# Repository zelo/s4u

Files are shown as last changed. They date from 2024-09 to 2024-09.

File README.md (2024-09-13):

Some information about Elegoo Saturn 4 Ultra

Everything is provided as is, I'm not responsible for any damage you cause to your hardware. Everything you do is at your own risk!

# Table of Contents

1. [G-code Documentation](gcode.md)
2. [Hardware Documentation](hardware.md)
3. [Anycubic Plate Adapter](anycubic_plate_adapter.md)

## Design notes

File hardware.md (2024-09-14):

# Hardware (from boot log analysis)

**Hardware Components**

| **Component** | **Details** | **Additional Information & Links** |
|---|---|---|
| **SoC** | **SigmaStar SSD202D** | - Dual-core ARM Cortex-A7 CPU<br>- 128 MB DDR RAM<br>- Integrated peripherals including Ethernet, USB, and more<br>- [SigmaStar SSD202D Documentation](https://github.com/iscle/SigmaStar-SSD202D-Docs/tree/main)<br>- [Linux Support Information](https://linux-chenxing.org/infinity2/#ssd202d) |
| **Storage** | **8 GB eMMC - Samsung KLM8G1GETF-B041** | - eMMC 5.1 standard<br>- High performance and reliability for embedded applications<br>- [Samsung KLM8G1GETF-B041 Product Page](https://semiconductor.samsung.com/estorage/emmc/emmc-5-1/klm8g1getf-b041/) |
| **FPGA** | **WILNX17 BG256** | - FPGA device by Jing Zhong Semiconductor<br>- Specific datasheet unavailable<br>- [WILNX17 BG256 Product Page](https://jingzhongsemi.com/cn/product/WILNX17.html) |
| **Wi-Fi Module** | **Realtek RTL8811CU** | - Supports 802.11ac Wi-Fi standard<br>- USB interface<br>- Provides wireless connectivity<br>- [Realtek RTL8811CU Product Page](https://www.realtek.com/en/products/communications-network-ics/item/rtl8811cu)<br>- [Datasheet](https://www.lcsc.com/datasheet/lcsc_datasheet_2302141730_Realtek-Semicon-RTL8811CU-CG_C2687136.pdf) |
| **Touchscreen** | **Goodix Capacitive Touchscreen (Goodix-TS 1-005d)** | - Identified in boot log<br>- Likely used for user input<br>- [Goodix Touchscreen Controllers](https://www.goodix.com/en/products/touchscreen-controllers) |
| **Display Panel** | **LCD Display with Resolution 480x800** | - Display output for user interface<br>- Rotation capabilities |
| **Camera** | **UVC-Compliant HD Camera (UC01 HD Camera)** | - USB-connected camera<br>- Used for monitoring or scanning<br>- [UVC Devices Information](https://www.kernel.org/doc/html/latest/userspace-api/media/uvcvideo.html) |
| **USB Ports** | **Multiple USB 2.0 EHCI Controllers** | - Enables connection of USB devices<br>- Managed by EHCI drivers |
| **Ethernet Interface** | **Ethernet Controller (sstar_emac)** | - Integrated Ethernet MAC in SoC<br>- Not exposed as port |
| **Stepper Motor Drivers** | **TMC2209 and FQ6630 Stepper Motor Drivers** | - Used for precise motor control<br>- Common in 3D printers for axis movement<br>- **TMC2209**: [Datasheet](https://www.trinamic.com/fileadmin/assets/Products/ICs_Documents/TMC2209_datasheet.pdf)<br>- **FQ6630**: Datasheet not readily available |
| **Temperature Sensor** | **Onboard Temperature Sensor** | - Monitors device temperature<br>- Reports around 30°C in logs |
| **I2C Devices** | **I2C Bus Devices** | - Communication with peripherals<br>- Notable error with device at address `0x82` |
| **GPIO Interfaces** | **General Purpose Input/Output Pins** | - Used for hardware control<br>- Configured during boot (`gpio debug` messages) |
| **Storage Partitions** | **Multiple MTD Partitions on SPI NAND Flash** | - 128 MiB SPI NAND Flash<br>- Partitions include `KERNEL`, `UBI`, etc. |
| **MMC Interfaces** | **MicroSD/MMC Card Interface** | - eMMC storage (`mmcblk0`)<br>- Supports additional storage options |

# Boot Log Analysis (based on boot.log file by ChatGPT)

1. Boot Process Overview

    The device undergoes the following boot sequence:

    Initial Program Loader (IPL): Begins with IPL g75a3331, indicating the bootloader version.
    U-Boot Bootloader:
        Version: U-Boot 2015.01
        Build Date: July 03, 2024
        Build Info: Build: jenkins-PPL_100-PACKAGE-OS-CL103-811
    Linux Kernel:
        Version: 4.9.84
        Build Date: July 03, 2024
        Processor: ARM Cortex-A7 (ARMv7 Processor [410fc075] revision 5)
    Filesystem:
        Root filesystem mounted as UBIFS from UBI volume.

2. Hardware Details

   CPU: ARM Cortex-A7 (dual-core)
   Memory:
   RAM: 128 MB
   eMMC Storage: 7.28 GiB (mmcblk0)
   Flash Storage:
   Type: SPI NAND (SPINAND)
   Size: 128 MiB
   Partitions: 13 MTD partitions (e.g., IPL0, UBOOT0, KERNEL, UBI)
   Peripherals:
   Touchscreen: Goodix Capacitive TouchScreen (Goodix-TS 1-005d)
   Camera: UVC-compliant camera detected (UC01 HD Camera)
   USB Ports: Multiple USB EHCI controllers initialized
   Network Interfaces:
   Ethernet: sstar_emac driver
   Wi-Fi: Realtek 802.11ac NIC (rtl8821cu driver)
   Sensors:
   Temperature Sensor: Reports temperatures around 30°C

3. Software Components

   Operating System: Embedded Linux
   Bootloader: U-Boot
   Kernel Modules:
   Various modules are attempted to load (e.g., exfat.ko, uvcvideo)
   Services and Applications:
   Networking: udhcpc DHCP client, Wi-Fi supplicant
   RTSP Server: Streams video from the camera
   WebSocket Listener: Runs on ws://0.0.0.0:3030/websocket
   Custom Applications: Indications of custom applications like ai_camera, sdcp_v3, and others

4. Device Functionality

    Based on the log entries, the device appears to be a 3D printer with the following features:

    Motion Control:
        Axes: References to axis, stepper, endstop, and homing procedures
        Motor Drivers: tmc2209, fq6630 (common stepper motor drivers)
    Printing Parameters:
        Layer Information: CurrentLayer, TotalLayer
        Print Screen: PrintScreen value indicates progress or status
    FPGA Integration:
        FPGA Initialization: Logs related to fpga, suggesting use for real-time control
    User Interface:
        Touchscreen Input: Goodix touchscreen driver initialized
        Display Output: References to framebuffer and display settings

5. Network Connectivity

   Wi-Fi Connection:
   Connects to a Wi-Fi network with DHCP
   Obtains IP address and DNS information
   Server Connections:
   Communicates with mms.chitubox.com, indicating possible firmware updates or telemetry
   Attempts to start services like ws_client_register

6. Errors and Warnings

   Service Startup Failures:
   syslogd, klogd, and mdev fail to start due to missing start-stop-daemon
   Logs:
   /etc/init.d/S01syslogd: line 16: start-stop-daemon: not found
   Similar errors for S02klogd and S10mdev
   Module Loading Failures:
   Unable to insert certain kernel modules
   Logs:
   insmod: can't insert '/config/modules/4.9.84/exfat.ko': No such file or directory
   Similar errors for videodev.ko, v4l2-common.ko, etc.
   Filesystem Mounting Issues:
   Errors mounting partitions with NTFS and exFAT filesystems
   Logs:
   NTFS signature is missing. Failed to mount '/dev/mmcblk0p1': Invalid argument
   FAT-fs (mmcblk0p1): utf8 is not a recommended IO charset for FAT filesystems
   I2C Communication Errors:
   Unable to communicate with a device at address 0x82
   Logs:
   ERROR: Bus[0] in ms_i2c_xfer_write: Slave dev NAK, Addr: 0x82
   USB Device Issues:
   Errors related to USB device descriptors
   Logs:
   usb_get_configuration_no: failed to get descriptor - too long: 1992
   Other Warnings:
   WARNING: Caches not enabled during DRAM initialization
   hctosys: unable to open rtc device (rtc0)

7. Recommendations

   Service Failures:
   Ensure that start-stop-daemon is installed and properly located in the system PATH.
   Verify scripts in /etc/init.d/ reference the correct paths.
   Kernel Modules:
   Check that all necessary kernel modules are present in /config/modules/4.9.84/.
   Rebuild or install missing modules if necessary.
   Filesystem Mounting:
   Install necessary filesystem drivers for NTFS and exFAT if support for these filesystems is required.
   Ensure that the mount command is used with correct options matching the filesystem type.
   I2C Device at Address 0x82:
   Investigate the device connected at I2C address 0x82.
   Check for hardware connectivity issues or device malfunctions.
   USB Devices:
   Ensure that connected USB devices are compatible and functioning correctly.
   Update USB drivers if necessary.

8. Additional Observations

   Device Identity:
   References to ELEGOO and CHITUBOX suggest the device is an ELEGOO 3D printer using Chitu firmware.
   Logs:
   curl url : https://mms.chitubox.com/mainboardVersionUpdate/getInfo.do7?machineType=ELEGOO
   Security Considerations:
   The boot log ends with a login prompt: (none) login:
   Ensure that default passwords are changed to secure the device.
   Consider disabling unnecessary services if not required.

9. Conclusion

    The boot log indicates that the device is a network-connected 3D printer with various peripherals and services. There
    are some issues during boot, primarily related to missing executables and kernel modules. Addressing these issues will
    improve system stability and functionality.

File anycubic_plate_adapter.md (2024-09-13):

# Adapter for anycubic Mono X plate (mine is from mono X 6K)

You will need to replace locking mechanism with insert (need ti print part, hex nut, 2 threaded inserts and 2 screws)
Adapter uses friction fit, I printed mine with PLA 5 walls, 100% infill on bambulab x1c and it fits perfectly.
Printer settings have to be adjusted to account for difference in height [See My Settings](examples/update.gcode)

1. [Step File](anycubic_plate_adapter.step)
2. Images
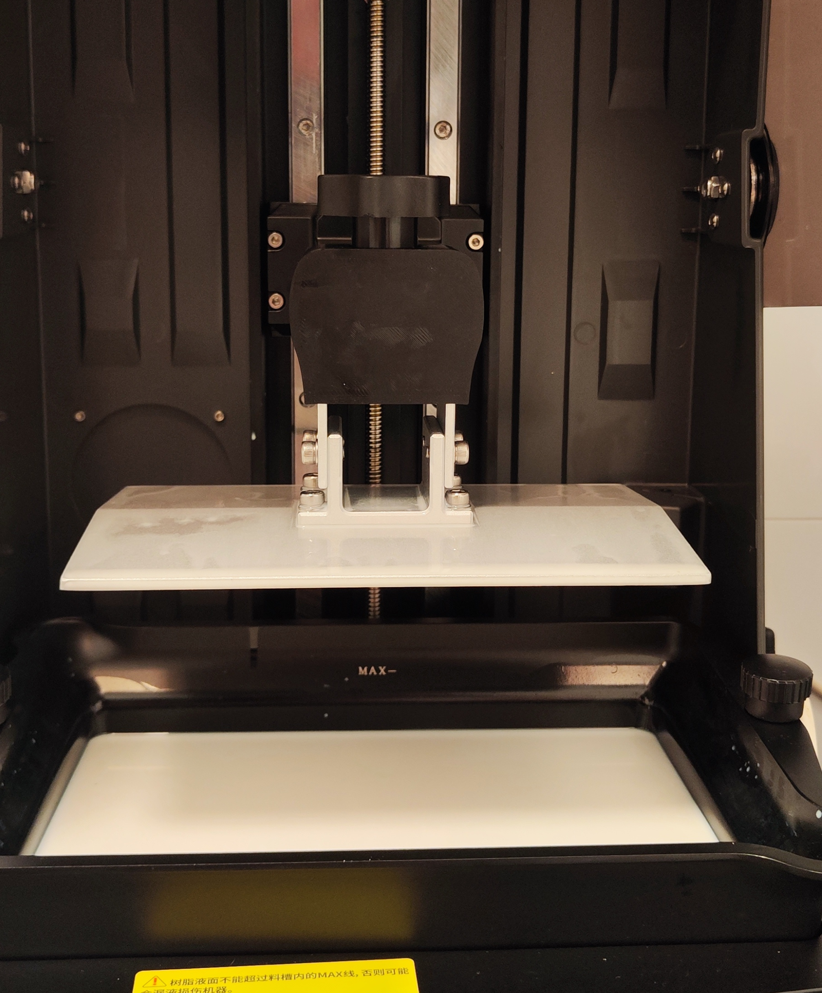
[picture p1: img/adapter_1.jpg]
adapter image 1
   
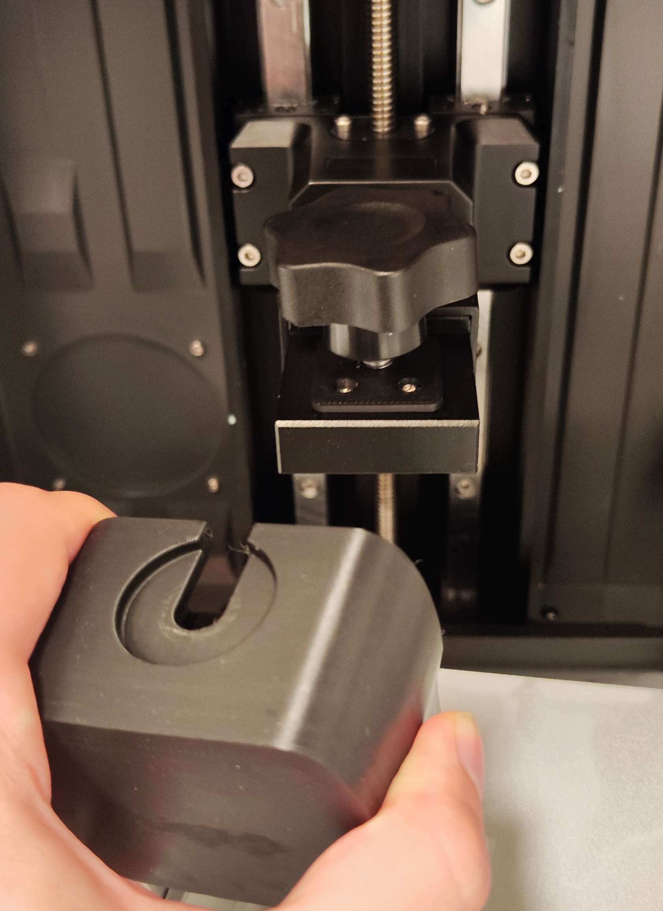
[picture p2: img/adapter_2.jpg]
adapter image 2
   
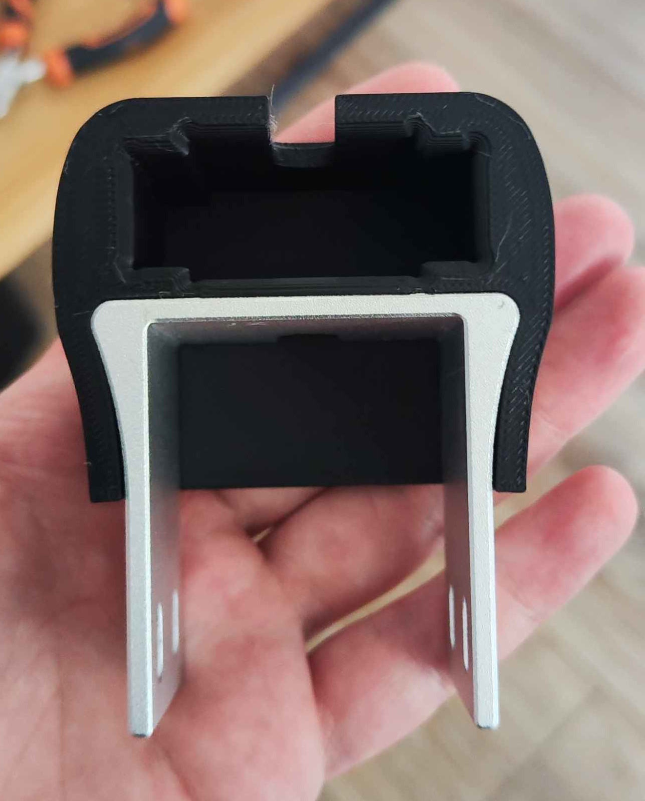
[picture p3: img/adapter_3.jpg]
adapter image 3
   
3. Results
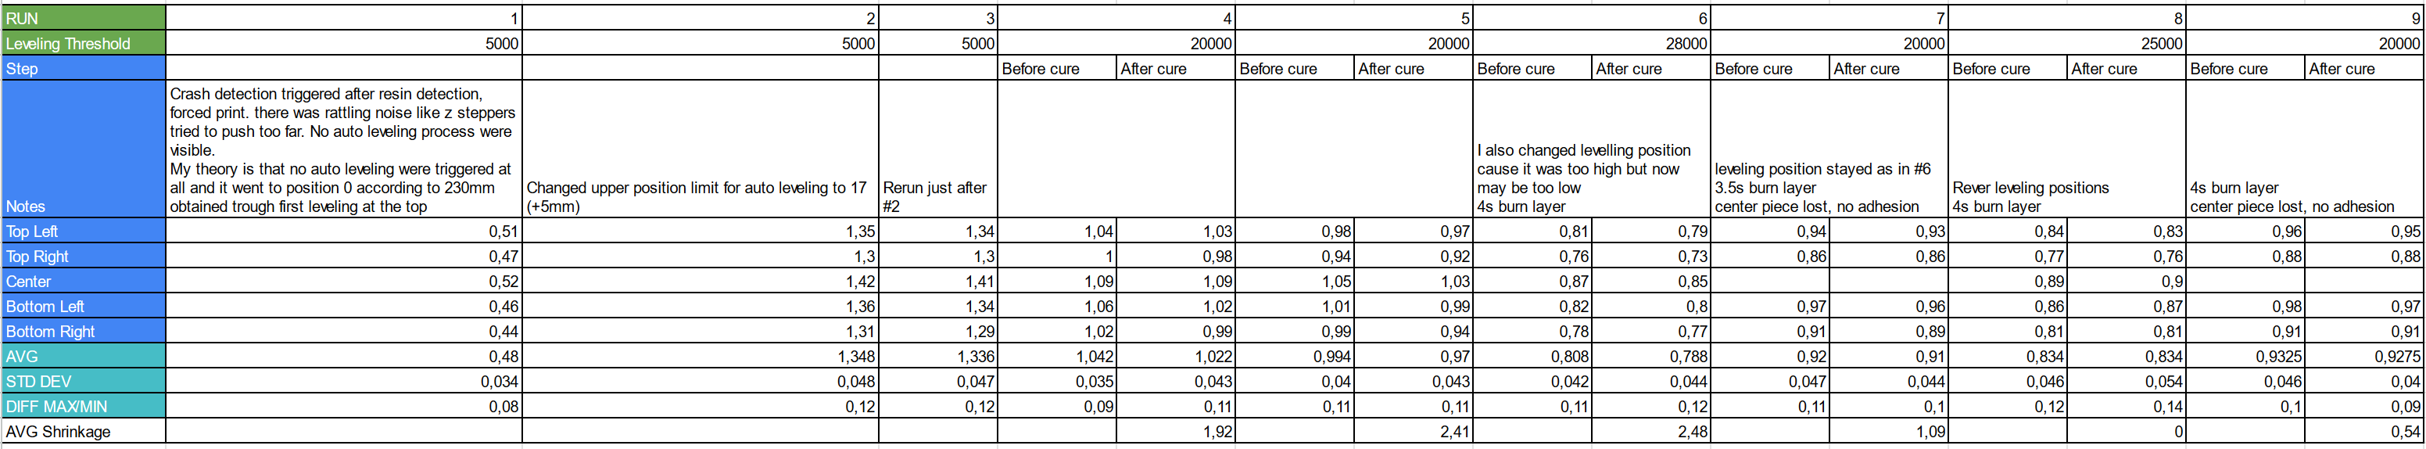
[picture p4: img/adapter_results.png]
Adapter Results


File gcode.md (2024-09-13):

# GCode settings

## **M5999 - Save and Export Machine Parameters**

The `M5999` command is used to manage the printer's configuration parameters, either saving them or exporting them to an
external storage device (such as a USB drive).

### **Command Structure:**

```
M5999 I<number> ; <comment>
```

- **M5999**: Command to either save or export the machine parameters.
- **I<number>**: Defines the action to be taken (save or export).
- **; <comment>**: Optional comment explaining the action.

### **Parameters:**

- **I0**: **Save machine parameters**
    - Example: `M5999 I0 ;保存参数`
    - **Translation**: "Save parameters"
    - **Description**: This command saves the current machine parameters to the printer's internal memory. These
      parameters include all the settings related to axis movements, motor currents, homing speeds, and other system
      configurations. The command ensures that the current configurations are stored and will persist after a restart.

- **I1**: **Export machine parameters to USB**
    - Example: `M5999 I1 ;导出机器参数`
    - **Translation**: "Export machine parameters"
    - **Description**: This command exports the current machine parameters to USB drive with
      filename `100MachineParams.gcode`.

---

### **Usage:**

1. **create `dump.gcode` file on usb with below content**
    ```
   M5999 I0;
   M5999 I1;
   ```

2. **Print this file on your printer**
3. **Open `100MachineParams.gcode` from USB on your PC**

Here’s a comprehensive and detailed breakdown of the `M5000` commands in your MSLA resin printer G-code configuration
file, including explanations for each parameter and possible use cases. This documentation will help you understand what
each command does and how it affects your printer.

---

# **MSLA Resin Printer G-code Command Documentation**

Sure! Below is a table that organizes the settings from your G-code dump, translating the Chinese comments into English
and grouping them by the domain they control.

---

### **Z-Axis Settings**

| Command | Parameters | Description |
|---|---|---|
| M5000 I0 A0 B230.000000 | B230.000000 | Z-axis travel distance (mm) |
| M5000 I0 A0 C20.000000 | C20.000000 | Maximum speed of Z-axis motor (mm/s) |
| M5000 I0 A0 D0.000625000000 | D0.000625000000 | Distance per step for Z-axis motor (mm/step) |
| M5000 I0 A0 E1 | E1 | Z-axis motor direction; 1 for positive, -1 for negative |
| M5000 I0 A0 F1 | F1 | Z-axis limit mode; 0: minimum limit, 1: maximum limit, 2: dual limit |
| M5000 I0 A0 S1 | S1 | Z-axis homing direction; 1 for positive, -1 for negative |
| M5000 I0 A0 P4.500000 | P4.500000 | First-stage homing speed for Z-axis (mm/s) |
| M5000 I0 A0 R1.000000 | R1.000000 | Second-stage homing speed for Z-axis (mm/s) |
| M5000 I0 A0 T0.000000 | T0.000000 | Reverse movement distance before Z-axis homing (mm); used to prevent collision if limit switch is far from physical zero point |
| M5000 I0 A0 X5.000000 | X5.000000 | Reverse movement distance after first limit trigger during Z-axis homing (mm) |
| M5000 I0 A0 Y0.450001 | Y0.450001 | Z-axis zero position |
| M5000 I0 A0 Z1 | Z1 | Z zero point and limit position setting; 0: same as limit position, 1: different from limit position |
| M5000 I5 A0 B0 | B0 | Z-axis minimum limit polarity; 0 for low-level trigger, 1 for high-level trigger |
| M5000 I5 A0 C0 | C0 | Z-axis maximum limit polarity; 0 for low-level trigger, 1 for high-level trigger |
| M5000 I5 A0 D5.000000 | D5.000000 | Z-axis acceleration (mm/s²) |
| M5000 I5 A0 E0.050000 | E0.050000 | Initial speed of Z-axis (mm/s) |
| M5000 I6 F9 | F9 | Z-axis motor current at idle (0-31); Current = (N+1)/32 * 2.5 A |
| M5000 I6 S18 | S18 | Z-axis motor operating current (0-31); Current = (N+1)/32 * 2.5 A |

### **X-Axis Settings**

| Command | Parameters | Description |
|---|---|---|
| M5000 I6 A12 | A12 | X-axis motor current at idle (0-31); Current = (N+1)/32 * 2.5 A |
| M5000 I6 B25 | B25 | X-axis motor operating current (0-31); Current = (N+1)/32 * 2.5 A |
| M5000 I6 C36.000000 | C36.000000 | X-axis acceleration (degrees/s²) |
| M5000 I6 D36.000000 | D36.000000 | X-axis deceleration (degrees/s²) |
| M5000 I6 E36.000000 | E36.000000 | Initial speed of X-axis (degrees/s) |
| M5000 I6 P1 | P1 | X-axis current change step value per time (1-31) |
| M5000 I6 R1000 | R1000 | X-axis current change interval (ms) |
| M5000 I0 A1 B140.000000 | B140.000000 | Total peeling angle of X-axis (degrees) |
| M5000 I0 A1 C900.000000 | C900.000000 | Maximum speed of X-axis motor (degrees/s) |
| M5000 I0 A1 D0.007031250000 | D0.007031250000 | Angle per step for X-axis motor (degrees/step) |
| M5000 I0 A1 E1 | E1 | X-axis motor direction; 1 for positive, -1 for negative |
| M5000 I0 A1 F1 | F1 | X-axis limit mode; 0: minimum limit, 1: maximum limit, 2: dual limit |
| M5000 I0 A1 S1 | S1 | X-axis homing direction; 1 for positive, -1 for negative |
| M5000 I0 A1 P36.000000 | P36.000000 | First-stage homing speed for X-axis (degrees/s) |
| M5000 I0 A1 R36.000000 | R36.000000 | Second-stage homing speed for X-axis (degrees/s) |
| M5000 I0 A1 T0.000000 | T0.000000 | Reverse movement angle before X-axis homing (degrees); used to prevent collision |
| M5000 I0 A1 X60.000000 | X60.000000 | Reverse movement angle after first limit trigger during X-axis homing (degrees) |
| M5000 I0 A1 Y0.000000 | Y0.000000 | X-axis zero position |
| M5000 I0 A1 Z1 | Z1 | X zero point and limit position setting; 0: same as limit position, 1: different from limit position |
| M5000 I5 A1 B0 | B0 | X-axis minimum limit polarity; 0 for low-level trigger, 1 for high-level trigger |
| M5000 I5 A1 C0 | C0 | X-axis maximum limit polarity; 0 for low-level trigger, 1 for high-level trigger |
| M5000 I201 C40.000000 | C40.000000 | Manual control speed of X-axis (degrees/s) |
| M5000 I201 D-10.000000 | D-10.000000 | Maximum zero position of X-axis; the range for adjustment after homing (degrees) |

### **Layer Settings for X-Axis**

| Command | Parameters | Description |
|---|---|---|
| M5000 I200 A36.000000 | A36.000000 | First-stage return speed before N layers (high speed) (degrees/s) |
| M5000 I200 B36.000000 | B36.000000 | Second-stage return speed before N layers (low speed) (degrees/s) |
| M5000 I200 C36.000000 | C36.000000 | First-stage peeling speed before N layers (low speed) (degrees/s) |
| M5000 I200 D36.000000 | D36.000000 | Second-stage peeling speed before N layers (high speed) (degrees/s) |
| M5000 I200 E0.000000  | E0.000000  | Second-stage return angle before N layers (degrees) |
| M5000 I200 F0.000000  | F0.000000  | First-stage peeling angle before N layers (degrees) |
| M5000 I200 S72.000000 | S72.000000 | First-stage return speed after N layers (high speed) (degrees/s) |
| M5000 I200 P72.000000 | P72.000000 | Second-stage return speed after N layers (low speed) (degrees/s) |
| M5000 I200 R72.000000 | R72.000000 | First-stage peeling speed after N layers (low speed) (degrees/s) |
| M5000 I200 T72.000000 | T72.000000 | Second-stage peeling speed after N layers (high speed) (degrees/s) |
| M5000 I200 X0.000000  | X0.000000  | Second-stage return angle after N layers (degrees) |
| M5000 I200 Y0.000000  | Y0.000000  | First-stage peeling angle after N layers (degrees) |
| M5000 I201 A1 | A1 | X-axis return mode; 0: limit method, 1: fixed angle |
| M5000 I201 B1 | B1 | Rotary peeling mode; 0: both motors move simultaneously, 1: X-axis motor moves first, then Z-axis |
| M5000 I201 E50 | E50 | N-layer value for X-axis |

### **Secondary Layer Settings for X-Axis (S2)**

| Command | Parameters  | Description |
|---|---|---|
| M5000 I210 A36.000000  | A36.000000  | S2: First-stage return speed before N layers (high speed) (degrees/s) |
| M5000 I210 B36.000000  | B36.000000  | S2: Second-stage return speed before N layers (low speed) (degrees/s) |
| M5000 I210 C36.000000  | C36.000000  | S2: First-stage peeling speed before N layers (low speed) (degrees/s) |
| M5000 I210 D36.000000  | D36.000000  | S2: Second-stage peeling speed before N layers (high speed) (degrees/s) |
| M5000 I210 E0.000000 | E0.000000 | S2: Second-stage return angle before N layers (degrees) |
| M5000 I210 F0.000000 | F0.000000 | S2: First-stage peeling angle before N layers (degrees) |
| M5000 I210 S144.000000 | S144.000000 | S2: First-stage return speed after N layers (high speed) (degrees/s) |
| M5000 I210 P144.000000 | P144.000000 | S2: Second-stage return speed after N layers (low speed) (degrees/s) |
| M5000 I210 R144.000000 | R144.000000 | S2: First-stage peeling speed after N layers (low speed) (degrees/s) |
| M5000 I210 T144.000000 | T144.000000 | S2: Second-stage peeling speed after N layers (high speed) (degrees/s) |
| M5000 I210 X0.000000 | X0.000000 | S2: Second-stage return angle after N layers (degrees) |
| M5000 I210 Y0.000000 | Y0.000000 | S2: First-stage peeling angle after N layers (degrees) |
| M5000 I211 A1 | A1 | S2: X-axis return mode; 0: limit method, 1: fixed angle |
| M5000 I211 B1 | B1 | S2: Rotary peeling mode; 0: both motors move simultaneously, 1: X-axis motor moves first, then Z-axis |
| M5000 I211 E50 | E50 | S2: N-layer value for X-axis |

### **Printing Completion and Pause Settings**

| Command | Parameters | Description |
|---|---|---|
| M5000 I1 A4.500000  | A4.500000  | Lifting speed after printing completion (mm/s) |
| M5000 I1 B60.000000 | B60.000000 | Relative distance lifted after printing completion (mm) |
| M5000 I1 C1 | C1 | Lifting mode after printing completion; 0: lift to highest point, 1: lift to specified relative distance, 2: no action |
| M5000 I1 D4.500000  | D4.500000  | Lifting speed after print pause (mm/s) |
| M5000 I1 E60.000000 | E60.000000 | Relative distance lifted after print pause (mm) |
| M5000 I1 F1 | F1 | Lifting mode after print pause; 0: lift to highest point, 1: lift to specified relative distance, 2: no action |
| M5000 I1 S4.500000  | S4.500000  | Lifting speed after print stop (mm/s) |
| M5000 I1 P60.000000 | P60.000000 | Relative distance lifted after print stop (mm) |
| M5000 I1 R1 | R1 | Lifting mode after print stop; 0: lift to highest point, 1: lift to specified relative distance, 2: no action |
| M5000 I1 T4.500000  | T4.500000  | Manual control speed (mm/s) |

### **Light Source and Fan Settings**

| Command | Parameters | Description |
|---|---|---|
| M5000 I2 B200  | B200 | Light source fan frequency |
| M5000 I2 C200  | C200 | Light source frequency |
| M5000 I2 D200  | D200 | Illumination frequency |
| M5000 I2 E3000 | E3000 | Buzzer frequency |
| M5000 I3 B2 | B2 | Light source fan mode; 0: always on, 1: off at startup, 2: follow print status, 3: follow exposure status |
| M5000 I3 C2 | C2 | Light source mode; 0: follow machine parameters, 1: follow print file, 2: combine both |
| M5000 I4 B255  | B255 | Light source fan PWM (0-255) |
| M5000 I4 C255  | C255 | Light source PWM (0-255) |
| M5000 I4 D255  | D255 | Illumination PWM (0-255) |
| M5000 I4 E100  | E100 | Buzzer volume (0-100) |
| M5000 I4 F0 | F0 | Screen orientation (0-3); 0: 0°, 1: 90°, 2: 180°, 3: 270° |
| M5000 I4 S180  | S180 | Time to enter screensaver (s) |
| M5000 I4 P5 | P5 | Time to enter grayscale screensaver (min) |

### **Temperature and Sensor Settings**

| Command | Parameters | Description |
|---|---|---|
| M5000 I7 A80 | A80 | Temperature protection upper limit (℃) |
| M5000 I7 B1  | B1 | Temperature detection disable; 0: disable, 1: enable |
| M5000 I8 A50 | A50 | Factory mode temperature sensor maximum value (℃) |
| M5000 I8 B0  | B0 | Factory mode temperature sensor minimum value (℃) |

### **Resin Detection and Calibration Settings**

| Command | Parameters  | Description |
|---|---|---|
| M5000 I4 R0 | R0 | Resin value estimation disable; 0: disable, 1: enable |
| M5000 I4 T870.000000 | T870.000000 | Maximum capacity of the vat (ml) |
| M5000 I4 X25.500000 | X25.500000  | Maximum abnormal line during actual resin detection stage (mm) |
| M5000 I4 Y4.000000 | Y4.000000 | Minimum abnormal line during actual resin detection stage (mm) |
| M5000 I203 B4.500000 | B4.500000 | Strain gauge calibration movement speed (mm/s) |
| M5000 I203 C30000 | C30000 | Maximum calibration time for strain gauge (ms) |
| M5000 I203 D5000 | D5000 | Strain gauge stationary judgment time (ms) |
| M5000 I203 E50 | E50 | Strain gauge stationary judgment threshold |
| M5000 I204 A45.000000  | A45.000000  | Resin detection starting position (mm); should be greater than the highest liquid level |
| M5000 I204 B2.000000 | B2.000000 | Resin detection ending position (mm); recommended 1mm or 2mm |
| M5000 I204 C0.050000 | C0.050000 | Resin detection step value (mm); recommended 0.05mm |
| M5000 I204 D2.500000 | D2.500000 | Resin detection movement speed (mm/s) |
| M5000 I204 E200 | E200 | Resin detection trigger threshold; recognized as liquid level when stress exceeds this value |
| M5000 I204 S143.000000 | S143.000000 | Vat width (mm); used for estimating volume based on detected liquid height |
| M5000 I204 P244.000000 | P244.000000 | Vat height (mm); used for estimating volume based on detected liquid height |
| M5000 I204 R100.000000 | R100.000000 | Compensation value for estimated resin detection volume (ml) |
| M5000 I205 A2.000000 | A2.000000 | Auto-leveling starting position (mm); should be greater than 1mm |
| M5000 I205 B-2.000000  | B-2.000000  | Auto-leveling ending position (mm); recommended -1mm |
| M5000 I205 C0.050000 | C0.050000 | Auto-leveling step value (mm); recommended 0.05mm |
| M5000 I205 D2.000000 | D2.000000 | Auto-leveling movement speed (mm/s); should not be too fast |
| M5000 I205 E28000 | E28000 | Auto-leveling threshold; normally greater than 0 |
| M5000 I206 C33000 | C33000 | Foreign object detection trigger threshold |
| M5000 I206 D1 | D1 | Resin detection probe switch |
| M5000 I206 E10 | E10 | Number of resin detection probes |
| M5000 I206 F-200 | F-200 | Minimum threshold for resin detection probes |
| M5000 I206 S200 | S200 | Maximum threshold for resin detection probes |

### **AI Camera and Time-lapse Settings**

| Command | Parameters  | Description |
|---|---|---|
| M5000 I208 A1 | A1 | AI camera detection switch; 0: off, 1: on |
| M5000 I208 B100.000000 | B100.000000 | AI camera detection position |
| M5000 I209 A1 | A1 | Time-lapse photography switch; 0: off, 1: on |
| M5000 I209 B50.000000  | B50.000000  | Model height threshold not to perform time-lapse photography |
| M5000 I209 C30.000000  | C30.000000  | Model height to start time-lapse photography |
| M5000 I209 D10 | D10 | Time-lapse photography interval layers |
| M5000 I209 E0 | E0 | Whether to move Z to zero position during manual homing; 0: no, 1: yes |
| M5000 I209 F1 | F1 | Whether to move X to zero position during manual homing; 0: no, 1: yes |
| M5000 I209 S10000 | S10000 | Time-lapse quick shot time (real time in ms) |
| M5000 I209 P70 | P70 | Interval time between time-lapse quick shots (ms) |

### **Printing Time Estimation Settings**

| Command | Parameters | Description |
|---|---|---|
| M5000 I212 A8420 | A8420 | Slow mode before N layers, X-axis movement time (ms) |
| M5000 I212 B4410 | B4410 | Slow mode after N layers, X-axis movement time (ms) |
| M5000 I212 C8420 | C8420 | Fast mode before N layers, X-axis movement time (ms) |
| M5000 I212 D2430 | D2430 | Fast mode after N layers, X-axis movement time (ms) |
| M5000 I212 E0 | E0 | Estimated print compensation time (ms); can be negative |

### **Save Parameters**

| Command  | Parameters | Description |
|---|---|---|
| M5999 I0 | I0 | Save machine parameters |

---

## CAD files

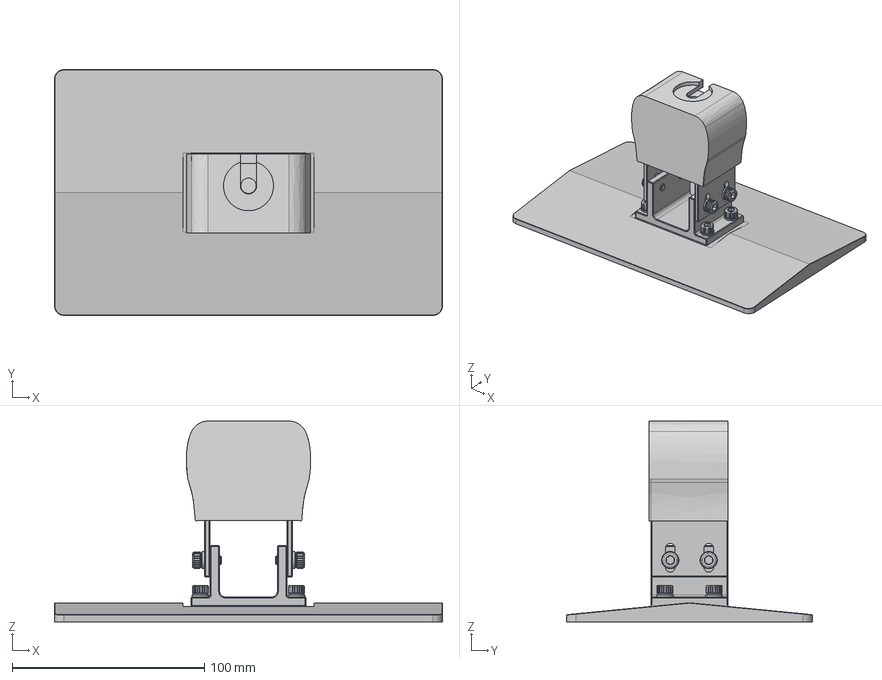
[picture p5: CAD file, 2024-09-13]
anycubic_plate_adapter.step
202.0 x 128.0 x 104.6 mm
90843A32 x 4
98689A114_GENERAL PURPOSE 18-8 STAINLESS STEEL WASHER(Mirror) (1) x 2
98689A114_GENERAL PURPOSE 18-8 STAINLESS STEEL WASHER x 4
90843A32(Mirror) x 2
98689A114_GENERAL PURPOSE 18-8 STAINLESS STEEL WASHER(Mirror) x 2
90843A32(Mirror) (1) x 2
mount
mount_top
